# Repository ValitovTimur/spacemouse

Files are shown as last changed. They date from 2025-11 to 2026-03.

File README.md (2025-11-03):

# SpaceMouse (fork): 6‑DOF мышь с 8 Hall‑датчиками и 5 кнопками (без энкодера и подсветки)

**Этот репозиторий — форк** проекта `AndunHH/spacemouse`.

**Целевой стенд:** Arduino Pro Micro (ATmega32U4, 5 V / 16 MHz) + **8 линейных Hall‑датчиков**, **5 физических кнопок** (3 базовые + Fn1 + Fn2). **Энкодера нет. LED‑кольца нет.**

**USB/HID API и формат отчётов полностью совместимы с апстримом** (эмуляция *SpaceMouse Pro Wireless (wired)*). Параметр‑меню, EEPROM и ProgMode по UART сохранены.

---

## Что изменено относительно апстрима

Репозиторий упрощён:

* Оставлены каталоги: **`spacemouse-keys/`**, **`testConfig/`**, **`Reverse-Engineering-Docs/`**, **`modifierFunctions/`**.
* Скрипты/утилиты, не влияющие на текущую сборку, удалены.

Изменения в коде (минимально инвазивно, без ломки API):

* **`spacemouse-keys/config.h`**

  * Профиль аппаратуры «8 Hall + 5 кнопок, без энкодера/LED».
  * Добавлены две новые кнопки в `KEYLIST` и увеличены `NUMKEYS`/`NUMHIDKEYS`.
  * Добавлены индексы модификаторов: `KEY_FN1_IDX`, `KEY_FN2_IDX`.
  * Введены три слоя раскладки HID‑кодов:

    * `BUTTONLIST` — базовый (1/2/3 и соло‑функции Fn).
    * `BUTTONLIST_FN1` — слой для комбо `Fn1 + [1|2|3]`.
    * `BUTTONLIST_FN2` — слой для комбо `Fn2 + [1|2|3]`.
  * Блок чувствительностей/инверсий/гейтов — по реальным замерам из консольного меню (`param::…`).

* **`spacemouse-keys/SpaceMouseHID.cpp`**

  * Переписана **`prepareKeyBytes()`**: корректная обработка **комбинаций** (Fn1/Fn2 + 1/2/3) **без «проскока» базовых кнопок** и **без «сдвоений»**.
  * Удержание (hold) любой кнопки/комбинации корректно **повторяет HID‑репорты** (для Shift/Ctrl/и т.п. на стороне ПК).

> HID‑дескриптор и идентификаторы устройства **не менялись** — драйверы 3Dconnexion/spacenavd видят устройство как раньше.

---

## Аппаратный профиль

* MCU: ATmega32U4 (Pro Micro, 5 V/16 MHz, Caterina).
* Датчики: 8 × линейных Hall (+ магниты/TPU пружины).
* Кнопки: 5 шт. (3 базовые + Fn1 + Fn2).
* Энкодер: **нет**.
* LED/Neopixel: **нет**.

---

## Структура репозитория

```
spacemouse-keys/              ← основной скетч, HID, калибровка, меню, конфиг
  ├─ spacemouse-keys.ino
  ├─ SpaceMouseHID.{h,cpp}    ← HID, сборка битов кнопок (patched)
  ├─ spaceKeys.{h,cpp}        ← чтение/дребезг/состояния клавиш (API без изменений)
  ├─ calibration.{h,cpp}
  ├─ kinematics.{h,cpp}
  ├─ parameterMenu.{h,cpp}
  ├─ config.h                  ← профиль этого форка (patched)
  └─ release.h

testConfig/
Reverse-Engineering-Docs/
modifierFunctions/
```

---

## Сборка и прошивка (Arduino IDE)

1. **Установить пакет SparkFun AVR Boards**
   Arduino IDE → *Board Manager* → найти **SparkFun AVR Boards** → *Install*.

2. **Заменить `boards.txt` из этого форка**
   В корне репозитория лежит `boards.txt`. Скопируй его **поверх** одноимённого файла в директории установленного пакета SparkFun AVR Boards (путь зависит от ОС/IDE), затем **перезапусти Arduino IDE**.

   Примеры путей:

   * **Windows (IDE 2.x):** `C:\Users\<user>\AppData\Local\Arduino15\packages\SparkFun\hardware\avr\<version>\boards.txt`
   * **Windows (IDE 1.8.x portable):** `<Arduino>\hardware\SparkFun\avr\boards.txt`
   * **Linux:** `~/.arduino15/packages/SparkFun/hardware/avr/<version>/boards.txt`
   * **macOS:** `~/Library/Arduino15/packages/SparkFun/hardware/avr/<version>/boards.txt`

3. **Открыть проект**
   `spacemouse-keys/spacemouse-keys.ino`.

4. **Выбрать плату и порт**
   Tools → Board → **SparkFun AVR Boards → Spacemouse (ATmega32U4, 5 V, 16 MHz)**.
   Tools → Port → выбрать твой COM/tty.

5. **Собрать и прошить**
   Нажать **Upload**. Если IDE не поймала окно бутлоадера, дважды быстро нажми **Reset** на Pro Micro (режим Caterina) и повтори Upload.

6. **Проверка через Serial** (необязательно)
   Открой Serial Monitor (115200 бод). Меню отладок/параметров — пункт **30**.

> **Важно:** конфигурация (`config.h`), терминальное меню (30), ProgMode и Serial‑API — **без изменений** и полностью совместимы с апстримом.

---

## Конфигурация: ключевые фрагменты

Ниже — выдержка из рабочего `config.h`. HID‑API полностью совместим с апстримом; расширение — только в части 5 кнопок и Fn‑слоёв.

```c
// Кол-во и пины физических кнопок
#define NUMKEYS    5
#define KEYLIST    {0, 1, 2, 14, 16}   // 3 базовые + Fn1 + Fn2 (под твои GPIO)

// Сколько HID-кнопок реально репортим (биты в 4 байтах отчёта)
#define NUMHIDKEYS 5

// Индексы Fn-кнопок в keyState[] (по порядку из KEYLIST)
#define KEY_FN1_IDX 3
#define KEY_FN2_IDX 4

// Базовый слой (без Fn): 1,2,3 + соло-действия Fn
#define BUTTONLIST      {SM_2,   SM_1,   SM_3,   SM_SHFT, SM_4}

// Слой Fn1: Fn1 + 1/2/3 → альтернативные коды
#define BUTTONLIST_FN1  {SM_FIT, SM_MENU, SM_ROT, SM_SHFT, SM_4}

// Слой Fn2: Fn2 + 1/2/3 → ещё один набор кодов
#define BUTTONLIST_FN2  {SM_CTRL, SM_ESC,  SM_ALT, SM_SHFT, SM_4}
```

Поведение:

* **Одиночная 1/2/3** — отправляется базовый HID‑код.
* **Fn1/Fn2 + 1/2/3** — отправляется **только** код из соответствующего Fn‑слоя (без лишнего базового клика).
* **Fn1/Fn2 в одиночку** — их соло‑действия берутся из `BUTTONLIST` (в примере: `SM_SHFT` и `SM_4`).
* **Удержание** кнопок/комбинаций — HID‑репорты продолжают идти (repeat/hold работает).

Остальной `config.h` (DEADZONE, MIN/MAX, чувствительности, инверсии, дрейф‑компенсация) — по апстриму, значения выставлены по замерам целевого девайса.

---

## Совместимость

* **USB/HID отчёты** идентичны апстриму — драйверы 3Dconnexion (Windows/macOS) и **spacenavd** (Linux) принимают устройство без изменений.
* **Параметр‑меню / EEPROM / ProgMode** — без изменений (меню `30` в сериалке; команды `>p`, `>r`, `>w`, `>s` и т.д.).

---

## Патч‑лист (файлы)

* `spacemouse-keys/config.h`

  * Расширение до 5 кнопок (`NUMKEYS`, `KEYLIST`, `NUMHIDKEYS`).
  * Добавлены `KEY_FN1_IDX`, `KEY_FN2_IDX`.
  * Добавлены `BUTTONLIST`, `BUTTONLIST_FN1`, `BUTTONLIST_FN2`.
  * Обновлены калибровки и чувствительности по реальным замерам.

* `spacemouse-keys/SpaceMouseHID.cpp`

  * Переписана `prepareKeyBytes()` под Fn‑слои; убраны «двойные» клики; корректен hold (повторение отчётов).

> Остальные исходники — как в апстриме; интерфейсы/структуры не менялись.

---

## Известные ограничения

* По умолчанию **отключены** энкодер и LED‑подсветка (можно включить обратно через `config.h`, но профиль форка — «8 Hall + 5 кнопок»).
* При увеличении числа кнопок: обновляйте `NUMKEYS`, `KEYLIST`, `NUMHIDKEYS` и все слои; следите, чтобы индексы Fn указывали на реальные позиции в `KEYLIST`.

---

## Лицензия и атрибуция

Лицензия наследована от апстрима: **CC BY‑NC‑SA 4.0**.

Апстрим: `AndunHH/spacemouse`. 3Dconnexion к проекту не аффилирована; USB‑протокол восстановлен обратной разработкой сообществом.

## Наладка и калибровка (c нуля до «ездит как надо»)

> Целевая аппаратная конфигурация этого форка: **8 HES**, **без энкодера/подсветки**, **5 кнопок (1/2/3 + Fn1/Fn2)**, прошивка — эмуляция **SpaceMouse Pro Wireless (cabled)**. Терминальное меню, ProgMode и формат параметров сохранены.

1. **Проверка разводки HES и полярностей**

   * Открой Serial‑монитор, нажми `Enter`, выбери режим **1** (или **10**) — «raw ADC».
   * Двигая ручку по одной оси, смотри, что шевелятся **ровно нужные пары** каналов (см. `PINLIST`).
   * Если при приближении магнита *значение растёт*, а должно **падать** — инвертируй соответствующую пару в `INVERTLIST` (обычно зеркально: `0&1`, `2&3`, `6&7`, `8&9`).
   * Повтори для всех трёх степеней свободы.

2. **Нулевая точка и «тихий» дрейф**

   * Режим **11** («Zeroing…»). Не трогай ручку, смотри предложенный `DEADZONE` и отметки *Axis not centered?*.
   * Поставь небольшую «мёртвую зону» — **3…6**. В конфиге: `#define DEADZONE N`, или через меню параметров (см. п. 7) → **Write to EEPROM**.

3. **Диапазоны MIN/MAX**

   * Режим **20** на ~20 с: активно покачай/пожми по всем осям.
   * Забери предложенные массивы `MINVALS`/`MAXVALS` и **впиши в `config.h`** (раздел «Third calibration»), **пересобери и залей**.
   * Признак, что диапазон занижен: в режимах 2/3/4 значения «упираются» раньше физического хода.

4. **Чувствительность**

   * Режим **4** (TX/TY/TZ/RX/RY/RZ). Добивайся, чтобы при полном ходе пики были в коридоре **±320…±350**.
   * Тюнинг: `SENS_TX/TY` (линейка), `SENS_PTZ/SENS_NTZ` (плюсовая/минусовая Z отдельно), `SENS_RX/RY/RZ` (повороты).
   * Вспомогательные «ворота»: `GATE_NTZ`, `GATE_RX/RY/RZ` — отрубает мелкий шум вокруг нуля (0 = выкл).

5. **Форма отклика (Modifier)**

   * `MODFUNC=0` — линейка.
   * `MODFUNC=1` — «квазиквадрат»: гасит мелочь вокруг нуля, оставляя контроль на больших отклонениях.
   * `MOD_A` влияет на «приплюснутость» у нуля (1.05…1.4), `MOD_B` — на рост к краю (1.1…1.35 для `MODFUNC=3`, но в этом форке по умолчанию **1**).
   * Проверяй в **3** (центрированные+deadzone) и **4** (скорости).

6. **Оси/инверсии/перестановки**

   * Если в САПР «влево» ощущается «вправо» — правь `INVX/INVY/INVZ` и `INVRX/INVRY/INVRZ`.
   * `SWITCHXY/SWITCHYZ` — обмен осей при надобности.
   * Для Windows + 3DxWare частые пресеты указаны в комментариях рядом с define’ами.

7. **Меню параметров и EEPROM (без перекомпиляции)**

   * Режим **30** → `1` (list), `2` (edit), `4` (write EEPROM), `7` (dump defines).
   * Порядок удобный: `2` — подправил / проверил в **4** — `4` (save) — при желании `7` (скопировал в `config.h`).

8. **Комбо‑кнопки (Fn1/Fn2 + 1/2/3)**

   * В этом форке реализованы слои: **база** (`BUTTONLIST`), **Fn1** (`BUTTONLIST_FN1`), **Fn2** (`BUTTONLIST_FN2`).
   * Соло‑нажатия Fn1/Fn2 отдают свои отдельные действия (настроены в базовом списке по индексам `KEY_FN1_IDX/KEY_FN2_IDX`).
   * Комбинации не «протекают» базовыми нажатиями; удержание поддерживает автоповтор на стороне HID.
   * Кнопки и слои задаются **в `config.h`**: `NUMKEYS`, `KEYLIST`, `NUMHIDKEYS`, `BUTTONLIST`, `BUTTONLIST_FN1`, `BUTTONLIST_FN2`, `KEY_FN1_IDX/KEY_FN2_IDX`.

9. **Дрифт‑компенсация**

   * Оставь мышь в покое: при `COMP_EN=1` нули подравниваются автоматически, не трогая твою «центровку» и чувствительности.
   * Тюнинг: `COMP_WAIT` (ожидание покоя), `COMP_NR` (длина усреднения), `COMP_MDIFF/COMP_CDIFF` (допустимые подвижки/смещения).

10. **Быстрый чек‑лист симптомов**

    * «Подвисает» одна из осей на краях → расширь `MINVALS/MAXVALS`.
    * Мелкая дрожь около нуля → чутка увеличь `DEADZONE` или `GATE_*`; подстрой `MODFUNC`.
    * Комбо срабатывают «двойным» нажатием → проверь актуальные файлы `spaceKeys.*` и `SpaceMouseHID.*` из форка (правки слоя/повтора/маски); при необходимости увеличь `DEBOUNCE_KEYS_MS`.

---

### Ручное центрирование (Fn1+Fn2)

Если устройство уже откалибровано, но «нулевая точка» немного уплыла, можно быстро пересвести ноль без пересборки и без потери чувствительности/диапазонов:

* **Зажмите одновременно Fn1 и Fn2 на ~2 секунды.**
* Сработает «мягкий zeroing»: вызывается та же логика, что и автокомпенсация дрейфа (re‑center), **не трогая** MIN/MAX, чувствительности, маппинг осей и EEPROM.
* Работает в любом режиме (в т.ч. вне меню), безопасно.

> Примечание: Авто‑zeroing (drift compensation) остаётся включённым и продолжает работать по заданным порогам `COMP_*`. Комбинация Fn1+Fn2 — это ручной триггер того же процесса, когда нужно «подровнять» ноль сразу.

## Справочник параметров (меню/EEPROM)

Ниже — параметры, видимые в **mode 30 → list/edit**. Типы: **INT**, **FLOAT**, **BOOL**.

#

### Комбинация Fn1+Fn2 — Zeroing

* **Что делает:** мгновенно инициирует мягкое центрирование (re‑center) как в авто‑компенсации дрейфа.
* **Что не делает:** не сбрасывает `MINVALS`/`MAXVALS`, не меняет `SENS_*`, `INV*`, не пишет в EEPROM.
* **Когда использовать:** если после длительной паузы ощущается микросмещение нуля — зажмите Fn1+Fn2 на ~2s.

## Движение и чувствительность

* **DEADZONE** *(INT)* — ширина «мертвой зоны» по центрированным значениям. Малые шумы в ноль. Реком.: **3…6**.
* **SENS_TX / SENS_TY** *(FLOAT)* — делитель чувствительности по X/Y трансляциям. **Меньше** → чувствительнее.
* **SENS_PTZ / SENS_NTZ** *(FLOAT)* — делители по **+Z / −Z** (раздельная калибровка «вниз/вверх»).
* **SENS_RX / SENS_RY / SENS_RZ** *(FLOAT)* — делители по поворотам (roll/pitch/yaw).
* **GATE_NTZ / GATE_RX / GATE_RY / GATE_RZ** *(INT)* — «ворота» около нуля; всё, что по модулю меньше — принудительно ноль. `0` = выкл.

### Модификатор кривой

* **MODFUNC** *(INT)* — 0: линейка; 1: `|x|^a·sign(x)`; 3: `tan(b·(|x|^a·sign(x)))/tan(b)` (в этом форке обычно 0/1).
* **MOD_A** *(FLOAT)* — экспонента «у нуля» (для 1 и 3). Больше → спокойнее около нуля. Типично **1.10…1.40**.
* **MOD_B** *(FLOAT)* — усиление к краям (для 3). Типично **1.10…1.35**.

### Направления/перестановки

* **INVX / INVY / INVZ / INVRX / INVRY / INVRZ** *(BOOL)* — инвертировать соответствующую ось.
* **SWITCHXY / SWITCHYZ** *(BOOL)* — обмен осей (перетасовать под конкретный софт/привычки).

### Эксклюзивный режим

* **EXCLUSIVE** *(BOOL)* — передавать **либо** трансляцию, **либо** вращение (что крупнее).
* **EXCL_HYST** *(INT)* — гистерезис, чтобы не «щёлкало» туда‑сюда (0 = выкл).
* **EXCL_PRIOZ** *(BOOL)* — «Z‑приоритет» для резистивных джойстиков (для HES обычно **0**).

### Дрифт‑компенсация (HES)

* **COMP_EN** *(BOOL)* — включить авто‑подравнивание нулей.
* **COMP_NR** *(INT)* — сколько выборок усреднять, когда устройство признано неподвижным.
* **COMP_WAIT** *(INT, ms)* — сколько ждать «тишину» перед компенсацией.
* **COMP_MDIFF** *(INT)* — предельная амплитуда дрожи «внутри окна», чтобы считать это дрейфом.
* **COMP_CDIFF** *(INT)* — доп. порог от центра: если ушли дальше — компенсацию не делать (считается реальным нажатием).

### Прочее

* **RAXIS_ECH / RAXIS_STR** — для режима «колесо как ось/клавиши» (у нас выключено, но параметры на месте для совместимости).

> Все эти параметры можно редактировать в **mode 30 → edit**, проверять в **mode 4**, сохранять в EEPROM (**mode 30 → write**), а затем выгружать текущие значения в виде `#define` (**mode 30 → list as defines**) для переноса в `config.h`.

---

> Примеры работы модификаторов кривой и подбор коэффициентов с визуализацией — в `modifierFunctions.html` (локальное HTML‑приложение, интерактивно демонстрирующее работу алгоритмов).

## Компиляция/линковка конфигурации кнопок (compile‑time)

Эти вещи **не** живут в EEPROM и задаются в `spacemouse-keys/config.h`:

* `NUMKEYS`, `KEYLIST` — сколько физических кнопок и на каких пинах.
* `NUMHIDKEYS` — сколько из них отдаём в HID‑массив.
* `BUTTONLIST` — базовый слой (индексы SM_* в HID‑отчёте).
* `BUTTONLIST_FN1`, `BUTTONLIST_FN2` — слои для комбо с Fn1/Fn2.
* `KEY_FN1_IDX`, `KEY_FN2_IDX` — индексы Fn‑кнопок (для соло‑действий и выбора слоя).
* `DEBOUNCE_KEYS_MS` — антидребезг.

После изменения этих `#define` → **пересборка и прошивка** обязательны.

## Button map (вид сверху контроллера)

Вид сверху (ориентир: USB сверху):

```
                                         USB
                                  -................
                KEY1              -              ..
                      .--      .........  . ........
                   .--. -+....                       ....
                  --.  ...        ...-.......-...        ...
                  .--..      ....                  ...       ..
     KEY2    .+.   .      ..                           ..      .
            +. .--     ..                                 ..     .
          --.  .     -.                                     ..     .
          +-. .    ..                .-------.                ..     .
            ..   ..             -.              ...             .    ..
       ... .    ..           ..                     ..           ..   ..
KEY3  .- .-.   ..          ..      .-..     ...       .           ..   ..
      -. ..   ..         .-     ..              ...     .          ..   ..
     .+  ..  ..         ..    ..                   ..    ..         ..   .
     .-+-.   -         ..   ..                      ..    ..        ..   ..
        ..  ..         .   ..                        ..    .         ..   .
       ..   -         -    .                          .    ..        ..   .
       ..   .         .    .                           .   ..         ..  .
       ..  ..         .    .                           -    .         ..  ..
       ..  ..         .    .                           -   ..         ..  ..
       ..  ..         -    .                          ..   ..         ..  .
        .   .         ..   ..                         .    ..         .   .
        ..  .          .    ..                       .    ..         ..   .
        ..  ..          .    ..                    ..    ..          ..  ..
         ..  .           ..    ..                ..     ..          ..   .
         ..   .            .      ..          .-.      -            .   .
          ..   .            ..                      ...            -   ..
           .    .              ..                 -.              -   ..
            ..   .                 .-..     .--.                 .   ..
              .   ..                                           ..   -+.
               .    ..                                       ..    .  --
                 .    .                                    ..   ..  .--
                   ..   ..                              ...    ..+---.   Fn1
                     ..    ...                      ....    ...    *
                        ...    .......       .......    .... --.
                           ....       .......       ...+-  .---
                                ....................     *--       Fn2
```

### Таблица соответствий

| Кнопка | Одиночное (Base) | С Fn1 | С Fn2 |
| --- | --- | --- | --- |
| KEY1 | **1** *(SM_1)* | **MENU** *(SM_MENU)*  | **ESC** *(SM_ESC)* |
| KEY2 | **2** *(SM_2)* | **FIT** *(SM_FIT)* | **CTRL** *(SM_CTRL)*  |
| KEY3 | **3** *(SM_3)* | **LOCK** *(SM_ROT)* | **ALT** *(SM_ALT)* |
| Fn1 | **SHIFT** *(SM_SHFT)* | — | **Fn1+Fn2 = Zeroing** |
| Fn2 | **4** *(SM_4)* | **Fn1+Fn2 = Zeroing** | — |

> **Примечания**
>
> * **Fn‑кнопки** работают как **модификаторы слоёв**: зажатый Fn1 или Fn2 временно переключает KEY1..KEY3 на альтернативные функции из соответствующего слоя. Одиночное нажатие Fn1/Fn2 тоже отправляет своё действие (см. таблицу).
> * **Fn1+Fn2** вместе запускают «Zeroing» (мягкое рецентрирование по дрейфу). Это **не** трогает MIN/MAX, чувствительности `SENS_*`, EEPROM-конфиг и т.п.; только пересчитывается текущий ноль, как при дрейф‑компенсации.
> * Раскладка изменяемая: при необходимости её можно настроить в `spacemouse-keys/config.h` через списки `BUTTONLIST`, `BUTTONLIST_FN1`, `BUTTONLIST_FN2` и индексы `KEY_FN1_IDX/KEY_FN2_IDX`. Для драйвера/ПО соответствия API показаны в скобках *(SM_…)*.

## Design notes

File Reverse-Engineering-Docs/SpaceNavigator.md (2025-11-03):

# Space Navigator
This page contains informations about a 3Dconnexion SpaceNavigator, which has been observed via wireshark:

`sudo modprobe usbmon` 
`sudo wireshark`

Test on update rate of the spacemouse with wireshark and spacenavd on ubuntu. src 1.8.1

## Data transmitted by Space Navigator
First package: (no translation seen here)
`01 00 00 00 00 00 00`

Second package: (rotation around "right down" = "second axis")
`02 00 00 e2 ff 00 00`

Pushing Button 1:
`03 01 00`

Releasing Button 1:
`03 00 00`

Pushing Button 2:
`03 02 00`

Release Button 2:
`03 00 00`

Pushing both buttons at the same time: 
`03 03 00`

If in spnavcfg the LED is turned on, the host sends to 1.8.2
`04 01`

Turning LED off:
`04 00`

## Timing of the data sent by Space Navigator
Report Id 1 for translation is sent.
8 ms later Report Id 2 for rotation is sent.
If keys are pressed: After 8 ms Report Id 3 is sent. Otherwise this is skipped and after 8 ms it restarts with Report Id 1.

This leads to a constant rate of 125 packages per second with alternating report id, as long there non-zero data.

After the last package with non-zero data, translation and rotation and sent three times with only zeros and in the steady 8 ms intervall.

## Device Descriptor of Space Navigator
```
DEVICE DESCRIPTOR
    bLength: 18
    bDescriptorType: 0x01 (DEVICE)
    bcdUSB: 0x0200
    bDeviceClass: Device (0x00)
    bDeviceSubClass: 0
    bDeviceProtocol: 0 (Use class code info from Interface Descriptors)
    bMaxPacketSize0: 8
    idVendor: Logitech, Inc. (0x046d)
    idProduct: 3Dconnexion Space Navigator 3D Mouse (0xc626)
    bcdDevice: 0x0435
    iManufacturer: 1
    iProduct: 2
    iSerialNumber: 0
    bNumConfigurations: 1
```

## HID Report of Space Navigator
See also [the wireshark protocoll](Reverse-Engineering-Docs/SpaceNavigator-Connected-Calibrate.pcapng) for a SpaceNavigator connected and pressed "calibrate" in the windows driver.

The HID following HID descriptor has been decoded with https://eleccelerator.com/usbdescreqparser/ 
```
0x05, 0x01,        // Usage Page (Generic Desktop Ctrls)
0x09, 0x08,        // Usage (Multi-axis Controller)
0xA1, 0x01,        // Collection (Application)
0xA1, 0x00,        //   Collection (Physical)
0x85, 0x01,        //     Report ID (1)
0x16, 0xA2, 0xFE,  //     Logical Minimum (-350)
0x26, 0x5E, 0x01,  //     Logical Maximum (350)
0x36, 0x88, 0xFA,  //     Physical Minimum (-1400)
0x46, 0x78, 0x05,  //     Physical Maximum (1400)
0x55, 0x0C,        //     Unit Exponent (-4)
0x65, 0x11,        //     Unit (System: SI Linear, Length: Centimeter)
0x09, 0x30,        //     Usage (X)
0x09, 0x31,        //     Usage (Y)
0x09, 0x32,        //     Usage (Z)
0x75, 0x10,        //     Report Size (16)
0x95, 0x03,        //     Report Count (3)
0x81, 0x06,        //     Input (Data,Var,Rel,No Wrap,Linear,Preferred State,No Null Position)
0xC0,              //   End Collection
0xA1, 0x00,        //   Collection (Physical)
0x85, 0x02,        //     Report ID (2)
0x09, 0x33,        //     Usage (Rx)
0x09, 0x34,        //     Usage (Ry)
0x09, 0x35,        //     Usage (Rz)
0x75, 0x10,        //     Report Size (16)
0x95, 0x03,        //     Report Count (3)
0x81, 0x06,        //     Input (Data,Var,Rel,No Wrap,Linear,Preferred State,No Null Position)
0xC0,              //   End Collection
0xA1, 0x02,        //   Collection (Logical)
0x85, 0x03,        //     Report ID (3)
0x05, 0x01,        //     Usage Page (Generic Desktop Ctrls)
0x05, 0x09,        //     Usage Page (Button)
0x19, 0x01,        //     Usage Minimum (0x01)
0x29, 0x02,        //     Usage Maximum (0x02)
0x15, 0x00,        //     Logical Minimum (0)
0x25, 0x01,        //     Logical Maximum (1)
0x35, 0x00,        //     Physical Minimum (0)
0x45, 0x01,        //     Physical Maximum (1)
0x75, 0x01,        //     Report Size (1)
0x95, 0x02,        //     Report Count (2)
0x81, 0x02,        //     Input (Data,Var,Abs,No Wrap,Linear,Preferred State,No Null Position)
0x95, 0x0E,        //     Report Count (14)
0x81, 0x03,        //     Input (Const,Var,Abs,No Wrap,Linear,Preferred State,No Null Position)
0xC0,              //   End Collection
0xA1, 0x02,        //   Collection (Logical)
0x85, 0x04,        //     Report ID (4)
0x05, 0x08,        //     Usage Page (LEDs)
0x09, 0x4B,        //     Usage (Generic Indicator)
0x15, 0x00,        //     Logical Minimum (0)
0x25, 0x01,        //     Logical Maximum (1)
0x95, 0x01,        //     Report Count (1)
0x75, 0x01,        //     Report Size (1)
0x91, 0x02,        //     Output (Data,Var,Abs,No Wrap,Linear,Preferred State,No Null Position,Non-volatile)
0x95, 0x01,        //     Report Count (1)
0x75, 0x07,        //     Report Size (7)
0x91, 0x03,        //     Output (Const,Var,Abs,No Wrap,Linear,Preferred State,No Null Position,Non-volatile)
0xC0,              //   End Collection
0x06, 0x00, 0xFF,  //   Usage Page (Vendor Defined 0xFF00)
0x09, 0x01,        //   Usage (0x01)
0xA1, 0x02,        //   Collection (Logical)
0x15, 0x80,        //     Logical Minimum (-128)
0x25, 0x7F,        //     Logical Maximum (127)
0x75, 0x08,        //     Report Size (8)
0x09, 0x3A,        //     Usage (0x3A)
0xA1, 0x02,        //     Collection (Logical)
0x85, 0x05,        //       Report ID (5)
0x09, 0x20,        //       Usage (0x20)
0x95, 0x01,        //       Report Count (1)
0xB1, 0x02,        //       Feature (Data,Var,Abs,No Wrap,Linear,Preferred State,No Null Position,Non-volatile)
0xC0,              //     End Collection
0xA1, 0x02,        //     Collection (Logical)
0x85, 0x06,        //       Report ID (6)
0x09, 0x21,        //       Usage (0x21)
0x95, 0x01,        //       Report Count (1)
0xB1, 0x02,        //       Feature (Data,Var,Abs,No Wrap,Linear,Preferred State,No Null Position,Non-volatile)
0xC0,              //     End Collection
0xA1, 0x02,        //     Collection (Logical)
0x85, 0x07,        //       Report ID (7)
0x09, 0x22,        //       Usage (0x22)
0x95, 0x01,        //       Report Count (1)
0xB1, 0x02,        //       Feature (Data,Var,Abs,No Wrap,Linear,Preferred State,No Null Position,Non-volatile)
0xC0,              //     End Collection
0xA1, 0x02,        //     Collection (Logical)
0x85, 0x08,        //       Report ID (8)
0x09, 0x23,        //       Usage (0x23)
0x95, 0x07,        //       Report Count (7)
0xB1, 0x02,        //       Feature (Data,Var,Abs,No Wrap,Linear,Preferred State,No Null Position,Non-volatile)
0xC0,              //     End Collection
0xA1, 0x02,        //     Collection (Logical)
0x85, 0x09,        //       Report ID (9)
0x09, 0x24,        //       Usage (0x24)
0x95, 0x07,        //       Report Count (7)
0xB1, 0x02,        //       Feature (Data,Var,Abs,No Wrap,Linear,Preferred State,No Null Position,Non-volatile)
0xC0,              //     End Collection
0xA1, 0x02,        //     Collection (Logical)
0x85, 0x0A,        //       Report ID (10)
0x09, 0x25,        //       Usage (0x25)
0x95, 0x07,        //       Report Count (7)
0xB1, 0x02,        //       Feature (Data,Var,Abs,No Wrap,Linear,Preferred State,No Null Position,Non-volatile)
0xC0,              //     End Collection
0xA1, 0x02,        //     Collection (Logical)
0x85, 0x0B,        //       Report ID (11)
0x09, 0x26,        //       Usage (0x26)
0x95, 0x01,        //       Report Count (1)
0xB1, 0x02,        //       Feature (Data,Var,Abs,No Wrap,Linear,Preferred State,No Null Position,Non-volatile)
0xC0,              //     End Collection
0xA1, 0x02,        //     Collection (Logical)
0x85, 0x13,        //       Report ID (19)
0x09, 0x2E,        //       Usage (0x2E)
0x95, 0x01,        //       Report Count (1)
0xB1, 0x02,        //       Feature (Data,Var,Abs,No Wrap,Linear,Preferred State,No Null Position,Non-volatile)
0xC0,              //     End Collection
0xC0,              //   End Collection
0xC0,              // End Collection

// 217 bytes

0000   05 01 09 08 a1 01 a1 00 85 01 16 a2 fe 26 5e 01   .............&^.
0010   36 88 fa 46 78 05 55 0c 65 11 09 30 09 31 09 32   6..Fx.U.e..0.1.2
0020   75 10 95 03 81 06 c0 a1 00 85 02 09 33 09 34 09   u...........3.4.
0030   35 75 10 95 03 81 06 c0 a1 02 85 03 05 01 05 09   5u..............
0040   19 01 29 02 15 00 25 01 35 00 45 01 75 01 95 02   ..)...%.5.E.u...
0050   81 02 95 0e 81 03 c0 a1 02 85 04 05 08 09 4b 15   ..............K.
0060   00 25 01 95 01 75 01 91 02 95 01 75 07 91 03 c0   .%...u.....u....
0070   06 00 ff 09 01 a1 02 15 80 25 7f 75 08 09 3a a1   .........%.u..:.
0080   02 85 05 09 20 95 01 b1 02 c0 a1 02 85 06 09 21   .... ..........!
0090   95 01 b1 02 c0 a1 02 85 07 09 22 95 01 b1 02 c0   ..........".....
00a0   a1 02 85 08 09 23 95 07 b1 02 c0 a1 02 85 09 09   .....#..........
00b0   24 95 07 b1 02 c0 a1 02 85 0a 09 25 95 07 b1 02   $..........%....
00c0   c0 a1 02 85 0b 09 26 95 01 b1 02 c0 a1 02 85 13   ......&.........
00d0   09 2e 95 01 b1 02 c0 c0 c0                        .........
```

# Other related stuff
## Device List for other devices
Check [ANTz wiki](https://github.com/openantz/antz/wiki/3D-Mouse#device-list) for a device list. 
Interestingly, our code is not fully compliant with this list, as we use event#1 and event#2 with 6 byte, despite we are suggesting to be a SpaceMouse Pro Wireless (cabled), which has only one 12 byte event#1.
This seems to be no problem, as our HID descriptor is declaring the values with report id#1 and id#2.

## About relative and absolute input data
[Full discussion](https://github.com/FreeSpacenav/spacenavd/issues/108)
> When I wrote the first version of spacenavd, I only had a space navigator, and the first version of spacenavd only worked with "relative" inputs because that was what the space navigator emitted. I'm saying "relative" in quotes because they weren't really relative, they were just reported as such, but the values were always absolute displacements per axis. 3Dconnexion probably realized at some stage that reporting them as "relative" is incorrect, and changed to absolute in newer devices. 
>
> I'm pretty sure all modern 3Dconnexion devices report absolute axis usage.

> The original Space Navigator reports it's data as relative positions. The original Space Navigator is very sensitive and is jiggling a lot i.e. the same value is only send repeatedly very for some milli-seconds.
>
> My emulated "SpaceMouse Pro Wireless (cabled)" (or at least our inherited) hid report descriptor reports absolute values
Our emulation is very sturdy and if you hold it in position, the same value are easily calculate for a second.
>
> When using spacenavd and the simple example, cube or even in FreeCAD:
>
>Relative reports are evaluated with every event, even if they are the same as before.
Absolute reports are only evaluated, if they differ from the previous report. This is merely visible with the SpaceNavigator, but is very annoying for our emulation, as it is reporting same values very often. I didn't figured out, if this dropping of events is done by spacenavd or linux itself...

> Solution: Change our emulated mouse to Relative Positions, even if this is not "up to date". But it avoids the necessity to jiggle the values.

## HID descriptor of a spacemouse wireless
See [SpaceMouseWireless.md](SpaceMouseWireless.md)

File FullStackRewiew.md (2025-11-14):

# Полный обзор правок и модификаций, которые нужно ввести.

## Схемотехника

  1. Однозначно фильтрацию входного питания. LC фильтр, защита от статики,
     перенапряжения, переполюсовки.
  2. Отделить ответвление питания датчиков Холла. LC фильтр, защита по току.
     Свивка жгута питания.
  3. Фильтр питания НА КАЖДОМ сенсоре прям у входа.
  4. Фильтрация выхода КАЖДОГО сенсора у входа в АЦП. Срезать все, что выше
     200 Гц. Точную частоту прикинуть исходя не из максимальной частоты
     перемещения джойстика (она крайне низка), а из времени фронта сигнала
     при максимальном создаваемом ускорении. Если выставить фильтр 10Гц
     (сомневаюсь что кто-то сможет дергать рукоятку быстрее), то управление
     может стать ватным, т.к. при быстром перемещении рукоятки, выходной сигнал
     будет дольше догонять уровень реального сигнала и управление будет ватным.
     Поэтому, смотреть частоту среза по фронту максимального ускорения. Это
     будет относительно грубый фильтр, чисто чтобы защитить от помех с питания
     и ВЧ наводок. Дальнейшая фильтрация в ПО.
  5. Свивка КАЖДОГО сигнального выхода сенсора с землей.
  6. Можно подумать о усилении и смещении полезного сигнала, для растягивания
     его на полный диапазон АЦП. Но не думаю что это нужно.
     6.1. Это приведет к сложной и индивидуальной настройке смещения под каждый
          сенсор, каждой мышке. Ну либо придумывать схемотехнику с ЦАП, где
          контроллер сам будет выставлять напряжение смещения и усиления.
     6.2. Схемотехника усложняется и увеличивается плата.
     Пока-что этот пункт не исполнять. Точности хватает и при текущей, дерьмовой
     схемоте, и на этапе первого прототипа не имеет смысла так вылизывать ее.
  7. Кол-во кнопок увеличить, сделать равным оригиналу. Кнопки тоже свивками,
     RC-фильтром и защитой по току. Все-таки выводы цифровые, в случае чего
     и пожечь можно.
  8. Обдумать возможность размещения ВСЕГО что есть, на плате, прямо под
     шайбой. Это кажется более чем осуществивым.

## ПО:

  По сути, тут уже все сделано. Я уже добавил возможность использования
  дополнительных 6-ти кнопок через комбинации.
  Нужно добавить еще программную фильтрацию данных (чтобы убрать дрож в процессе
  перемещения и убрать дрожание при затухающих колебаниях рукоятки).
  Фильтрацию разумно разместить не напрямую на анлоговых данных, а между уже
  рассчитаными перемещениями\вращениями по координатам и дополнительными
  модиффикаторами перемещений, нелинейных зависимостей и т.д.
  То есть, фильтровать не сам сигнал, а рассчитаные величины. Это более
  предсказуемо.

## Эргономика

  1. В основном, вся работа уже проделана.
     1.1. Рукоятку - скопировать.
     1.2. Основание рукоятки - скопировать (вот это углубление, в которое она
          входит).
     1.3. Пружину - однозначно скопировать. Идея печатной пружины и на столько
          простой механики - это супер круто. Пожал бы руку тому, кто догадался
          и провел эксперименты.
     1.4. Основание - переработать.
          1.4.1. Кнопки - увеличить кол-во, сменить сам тип кнопки на что-то
                 более мягкое, и сместить под пальцы.
          1.4.2. Сделать подставку под руку. В идеале - съемную.
                 Например, сделать ее круговой подставкой, в которую помещается
                 текущая "шайба". Можно попробовать подумать над смещением
                 кнопок на нее, и подключение этих кнопок через POGO пины.
                 ЕБАТЬ! ВОТ ОНО! Можно оставить 5 кнопок на шайбе, а остальные
                 переместить на подставку и Pogo пины.
                 Тогда хоткеи будут полностью совместимы.
  2. Чехол. Однозначно нужно сделать, скорее всего из TPU, должен закрывать
     рукоятку, но не касаться ее, а вот на шайбу должен натягиваться, чтобы
     за нее держаться. Можно сделать сужение, чтобы оно зацеплялось за основание.

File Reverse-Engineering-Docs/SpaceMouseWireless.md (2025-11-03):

# SpaceMouse Wireless
This page contains informations about a 3Dconnexion Space Mouse Wireless, which has been observed via wireshark:

SpaceMouse Wirelss HID Report
Recorded with Wireshark. 
Decoded with https://eleccelerator.com/usbdescreqparser/

## Update Rate
In move_and_rot.pcapng:
The translation and rotation seem to be sent at a speed of 12.5 packets each 200 ms = 62,5 packets/s = 16 ms update rate.

## Buttons and LEDs
Not further analysed jet, but seems to conform to [SpaceNavigator.](SpaceNavigator.md). I.e.: Report 3 rot keys, Report 4 for LED.

## Other findings
From other records: Report 0x17 reports the battery

    Report ID: 0x17
    0110 0100 = Usage: Battery Strength: 100 
    Vendor Data: 01
    Padding: 00

## Device Descriptor
```
DEVICE DESCRIPTOR
    bLength: 18
    bDescriptorType: 0x01 (DEVICE)
    bcdUSB: 0x0200
    bDeviceClass: Device (0x00)
    bDeviceSubClass: 0
    bDeviceProtocol: 0 (Use class code info from Interface Descriptors)
    bMaxPacketSize0: 32
    idVendor: 3Dconnexion (0x256f)
    idProduct: SpaceMouse Wireless (cabled) (0xc62e)
    bcdDevice: 0x0441
    iManufacturer: 1
    iProduct: 2
    iSerialNumber: 0
    bNumConfigurations: 1
```

## HID Report of SpaceMouse Wireless
```
0x05, 0x01,        // Usage Page (Generic Desktop Ctrls)
0x09, 0x08,        // Usage (Multi-axis Controller)
0xA1, 0x01,        // Collection (Application)
0xA1, 0x00,        //   Collection (Physical)
0x85, 0x01,        //     Report ID (1)
0x16, 0xA2, 0xFE,  //     Logical Minimum (-350)
0x26, 0x5E, 0x01,  //     Logical Maximum (350)
0x36, 0x88, 0xFA,  //     Physical Minimum (-1400)
0x46, 0x78, 0x05,  //     Physical Maximum (1400)
0x55, 0x0C,        //     Unit Exponent (-4)
0x65, 0x11,        //     Unit (System: SI Linear, Length: Centimeter)
0x09, 0x30,        //     Usage (X)
0x09, 0x31,        //     Usage (Y)
0x09, 0x32,        //     Usage (Z)
0x09, 0x33,        //     Usage (Rx)
0x09, 0x34,        //     Usage (Ry)
0x09, 0x35,        //     Usage (Rz)
0x75, 0x10,        //     Report Size (16)
0x95, 0x06,        //     Report Count (6)
0x81, 0x02,        //     Input (Data,Var,Abs,No Wrap,Linear,Preferred State,No Null Position)
0xC0,              //   End Collection
0xA1, 0x02,        //   Collection (Logical)
0x85, 0x03,        //     Report ID (3)
0x05, 0x01,        //     Usage Page (Generic Desktop Ctrls)
0x05, 0x09,        //     Usage Page (Button)
0x19, 0x01,        //     Usage Minimum (0x01)
0x29, 0x02,        //     Usage Maximum (0x02)
0x15, 0x00,        //     Logical Minimum (0)
0x25, 0x01,        //     Logical Maximum (1)
0x35, 0x00,        //     Physical Minimum (0)
0x45, 0x01,        //     Physical Maximum (1)
0x75, 0x01,        //     Report Size (1)
0x95, 0x02,        //     Report Count (2)
0x81, 0x02,        //     Input (Data,Var,Abs,No Wrap,Linear,Preferred State,No Null Position)
0x95, 0x0E,        //     Report Count (14)
0x81, 0x03,        //     Input (Const,Var,Abs,No Wrap,Linear,Preferred State,No Null Position)
0xC0,              //   End Collection
0xA1, 0x02,        //   Collection (Logical)
0x85, 0x04,        //     Report ID (4)
0x05, 0x08,        //     Usage Page (LEDs)
0x09, 0x4B,        //     Usage (Generic Indicator)
0x15, 0x00,        //     Logical Minimum (0)
0x25, 0x01,        //     Logical Maximum (1)
0x95, 0x01,        //     Report Count (1)
0x75, 0x01,        //     Report Size (1)
0x91, 0x02,        //     Output (Data,Var,Abs,No Wrap,Linear,Preferred State,No Null Position,Non-volatile)
0x95, 0x01,        //     Report Count (1)
0x75, 0x07,        //     Report Size (7)
0x91, 0x03,        //     Output (Const,Var,Abs,No Wrap,Linear,Preferred State,No Null Position,Non-volatile)
0xC0,              //   End Collection
0xA1, 0x02,        //   Collection (Logical)
0x85, 0x17,        //     Report ID (23)
0x15, 0x00,        //     Logical Minimum (0)
0x25, 0x64,        //     Logical Maximum (100)
0x55, 0x00,        //     Unit Exponent (0)
0x65, 0x00,        //     Unit (None)
0x05, 0x06,        //     Usage Page (Generic Dev Ctrls)
0x09, 0x20,        //     Usage (Battery Strength)
0x75, 0x08,        //     Report Size (8)
0x95, 0x01,        //     Report Count (1)
0x81, 0x02,        //     Input (Data,Var,Abs,No Wrap,Linear,Preferred State,No Null Position)
0x15, 0x00,        //     Logical Minimum (0)
0x25, 0x01,        //     Logical Maximum (1)
0x06, 0x00, 0xFF,  //     Usage Page (Vendor Defined 0xFF00)
0x09, 0x27,        //     Usage (0x27)
0x75, 0x01,        //     Report Size (1)
0x95, 0x01,        //     Report Count (1)
0x81, 0x02,        //     Input (Data,Var,Abs,No Wrap,Linear,Preferred State,No Null Position)
0x75, 0x07,        //     Report Size (7)
0x81, 0x03,        //     Input (Const,Var,Abs,No Wrap,Linear,Preferred State,No Null Position)
0xC0,              //   End Collection
0x06, 0x00, 0xFF,  //   Usage Page (Vendor Defined 0xFF00)
0x09, 0x01,        //   Usage (0x01)
0xA1, 0x02,        //   Collection (Logical)
0x15, 0x80,        //     Logical Minimum (-128)
0x25, 0x7F,        //     Logical Maximum (127)
0x75, 0x08,        //     Report Size (8)
0x09, 0x3A,        //     Usage (0x3A)
0xA1, 0x02,        //     Collection (Logical)
0x85, 0x05,        //       Report ID (5)
0x09, 0x20,        //       Usage (0x20)
0x95, 0x01,        //       Report Count (1)
0xB1, 0x02,        //       Feature (Data,Var,Abs,No Wrap,Linear,Preferred State,No Null Position,Non-volatile)
0xC0,              //     End Collection
0xA1, 0x02,        //     Collection (Logical)
0x85, 0x06,        //       Report ID (6)
0x09, 0x21,        //       Usage (0x21)
0x95, 0x01,        //       Report Count (1)
0xB1, 0x02,        //       Feature (Data,Var,Abs,No Wrap,Linear,Preferred State,No Null Position,Non-volatile)
0xC0,              //     End Collection
0xA1, 0x02,        //     Collection (Logical)
0x85, 0x07,        //       Report ID (7)
0x09, 0x22,        //       Usage (0x22)
0x95, 0x01,        //       Report Count (1)
0xB1, 0x02,        //       Feature (Data,Var,Abs,No Wrap,Linear,Preferred State,No Null Position,Non-volatile)
0xC0,              //     End Collection
0xA1, 0x02,        //     Collection (Logical)
0x85, 0x08,        //       Report ID (8)
0x09, 0x23,        //       Usage (0x23)
0x95, 0x07,        //       Report Count (7)
0xB1, 0x02,        //       Feature (Data,Var,Abs,No Wrap,Linear,Preferred State,No Null Position,Non-volatile)
0xC0,              //     End Collection
0xA1, 0x02,        //     Collection (Logical)
0x85, 0x09,        //       Report ID (9)
0x09, 0x24,        //       Usage (0x24)
0x95, 0x07,        //       Report Count (7)
0xB1, 0x02,        //       Feature (Data,Var,Abs,No Wrap,Linear,Preferred State,No Null Position,Non-volatile)
0xC0,              //     End Collection
0xA1, 0x02,        //     Collection (Logical)
0x85, 0x0A,        //       Report ID (10)
0x09, 0x25,        //       Usage (0x25)
0x95, 0x07,        //       Report Count (7)
0xB1, 0x02,        //       Feature (Data,Var,Abs,No Wrap,Linear,Preferred State,No Null Position,Non-volatile)
0xC0,              //     End Collection
0xA1, 0x02,        //     Collection (Logical)
0x85, 0x0B,        //       Report ID (11)
0x09, 0x26,        //       Usage (0x26)
0x95, 0x01,        //       Report Count (1)
0xB1, 0x02,        //       Feature (Data,Var,Abs,No Wrap,Linear,Preferred State,No Null Position,Non-volatile)
0xC0,              //     End Collection
0xA1, 0x02,        //     Collection (Logical)
0x85, 0x13,        //       Report ID (19)
0x09, 0x2E,        //       Usage (0x2E)
0x95, 0x01,        //       Report Count (1)
0xB1, 0x02,        //       Feature (Data,Var,Abs,No Wrap,Linear,Preferred State,No Null Position,Non-volatile)
0xC0,              //     End Collection
0xA1, 0x02,        //     Collection (Logical)
0x85, 0x19,        //       Report ID (25)
0x09, 0x31,        //       Usage (0x31)
0x95, 0x04,        //       Report Count (4)
0xB1, 0x02,        //       Feature (Data,Var,Abs,No Wrap,Linear,Preferred State,No Null Position,Non-volatile)
0xC0,              //     End Collection
0xA1, 0x02,        //     Collection (Logical)
0x85, 0x1A,        //       Report ID (26)
0x09, 0x32,        //       Usage (0x32)
0x95, 0x07,        //       Report Count (7)
0xB1, 0x02,        //       Feature (Data,Var,Abs,No Wrap,Linear,Preferred State,No Null Position,Non-volatile)
0xC0,              //     End Collection
0xC0,              //   End Collection
0xC0,              // End Collection
// 270 bytes
```

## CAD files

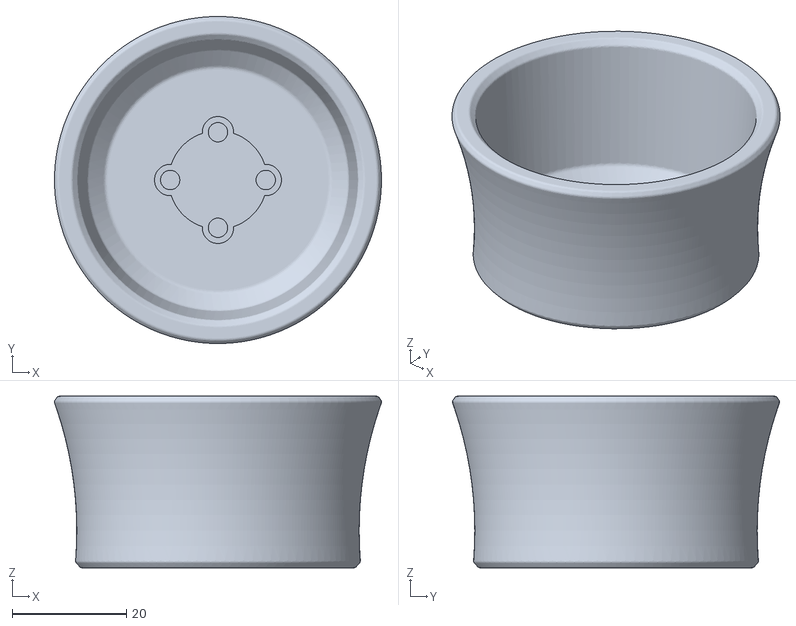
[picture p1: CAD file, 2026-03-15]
3D/Spacemouse+V1+bbla1_stls/obj_5_Knob.stl
57.1 x 57.1 x 30.0

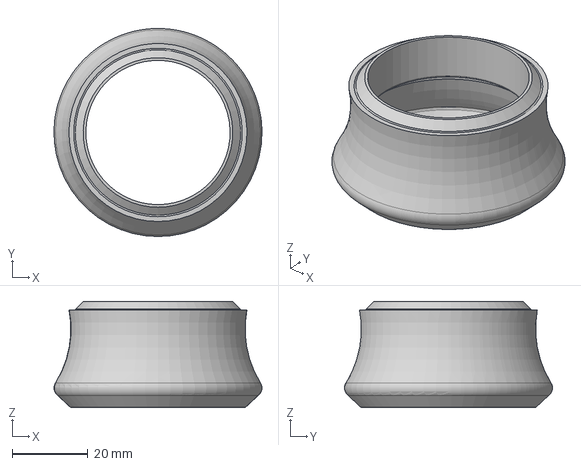
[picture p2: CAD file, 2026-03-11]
3D/TestPrint/Handle.stp
54.8 x 54.8 x 28.0 mm

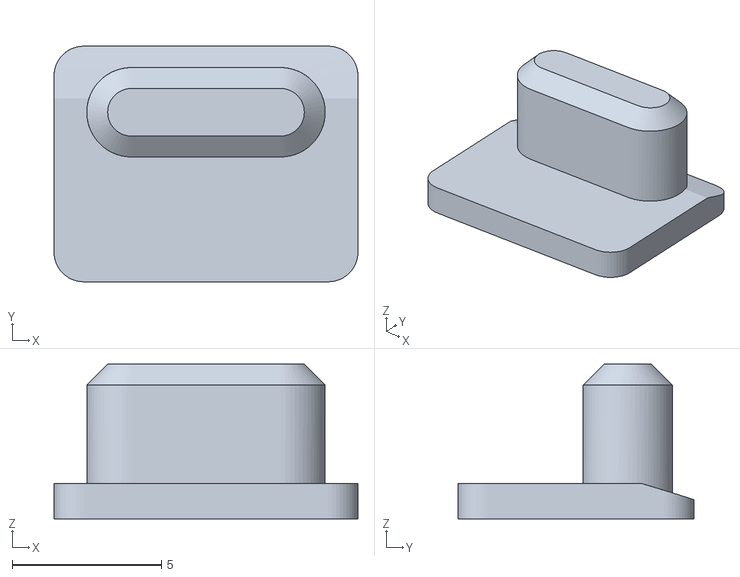
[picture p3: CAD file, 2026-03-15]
3D/Spacemouse+V1+bbla1_stls/obj_4_small buttons.stl
10.2 x 7.91 x 5.19

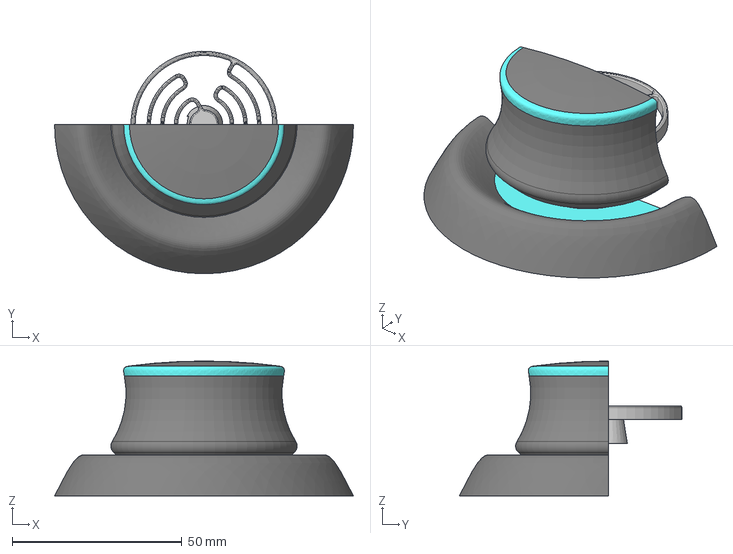
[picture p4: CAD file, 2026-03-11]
3D/TestPrint/SpaceMouse.stp
88.0 x 65.5 x 39.7 mm

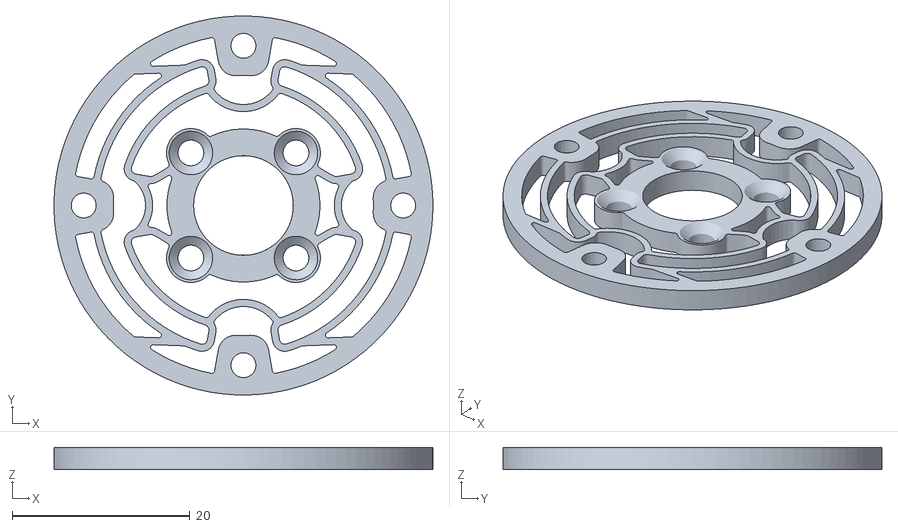
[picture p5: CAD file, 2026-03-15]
3D/Spacemouse+V1+bbla1_stls/obj_22_medium spring.stl
42.6 x 42.6 x 2.50

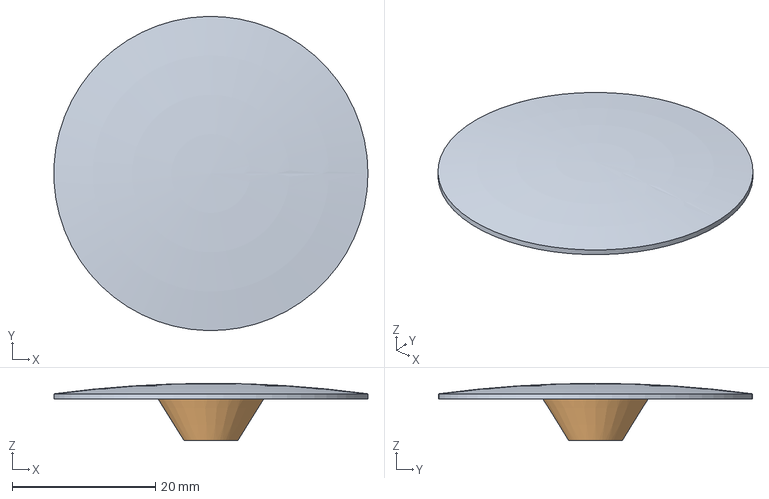
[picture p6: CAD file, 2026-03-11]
3D/TestPrint/HandleCap.stp
43.9 x 43.9 x 8.01 mm

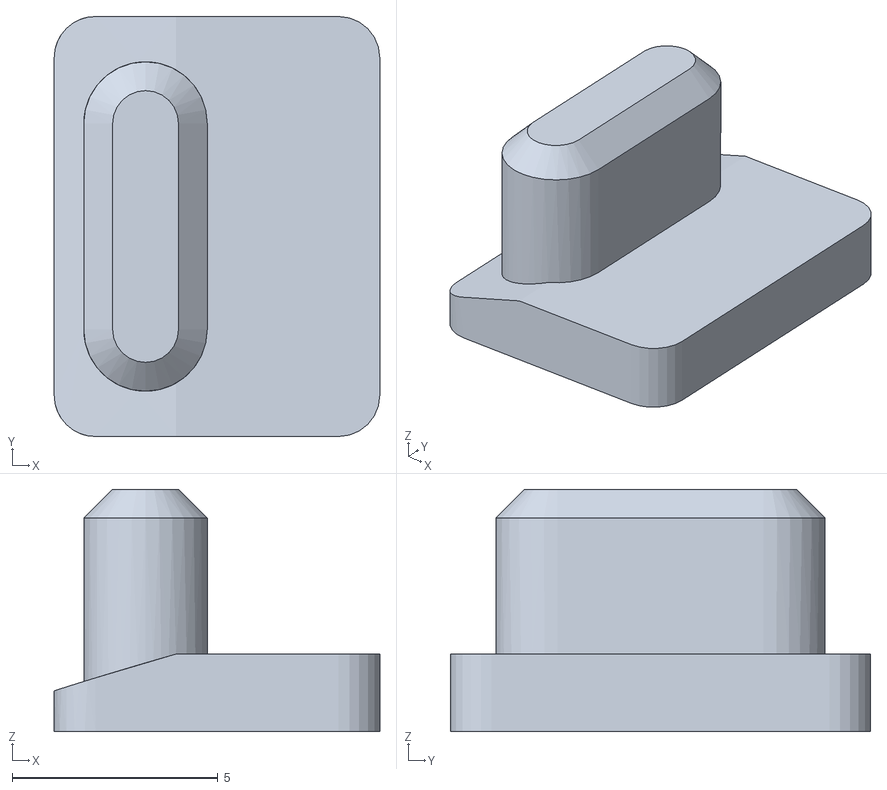
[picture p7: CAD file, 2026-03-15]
3D/Spacemouse+V1+bbla1_stls/obj_23_button 1.stl
7.91 x 10.2 x 5.89

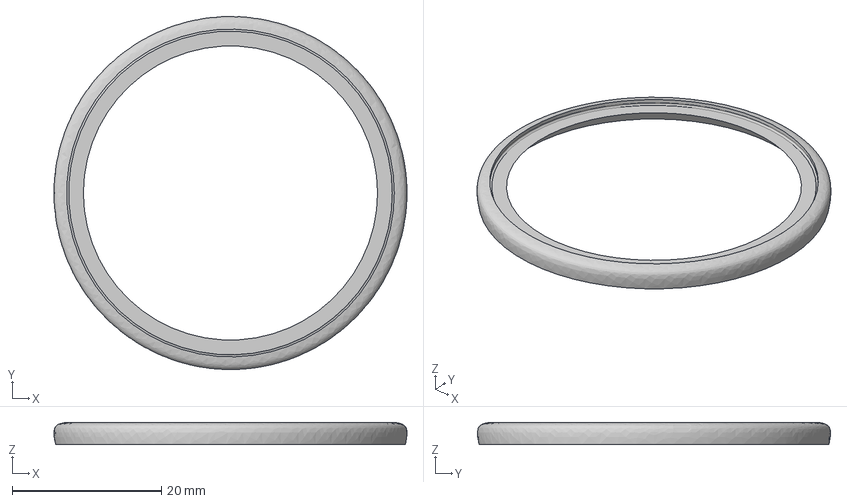
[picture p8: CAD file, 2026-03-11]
3D/TestPrint/HandleRing.stp
47.3 x 47.3 x 3.00 mm

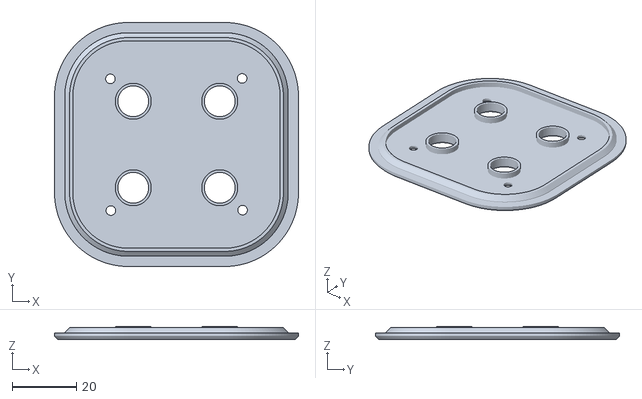
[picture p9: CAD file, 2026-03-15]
3D/Spacemouse+V1+bbla1_stls/obj_7_base cap.stl
76.0 x 76.0 x 4.00

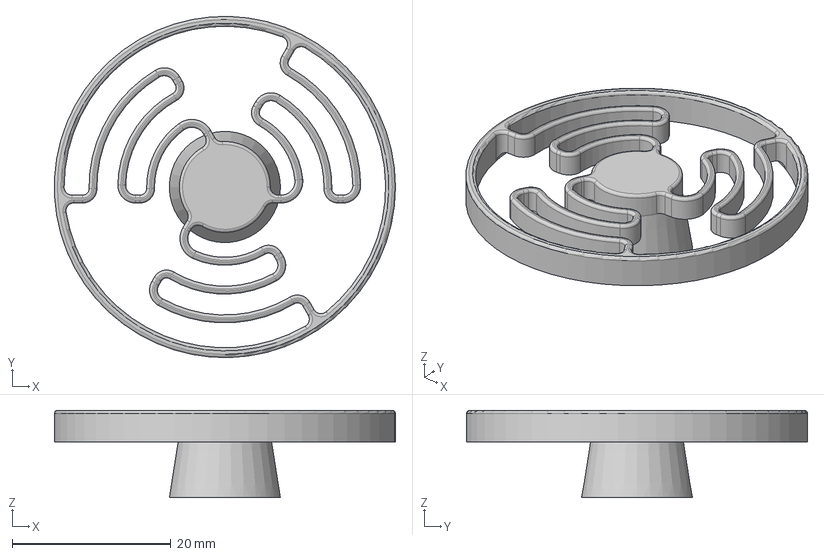
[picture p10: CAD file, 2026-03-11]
3D/TestPrint/Spring.stp
43.0 x 43.0 x 11.0 mm

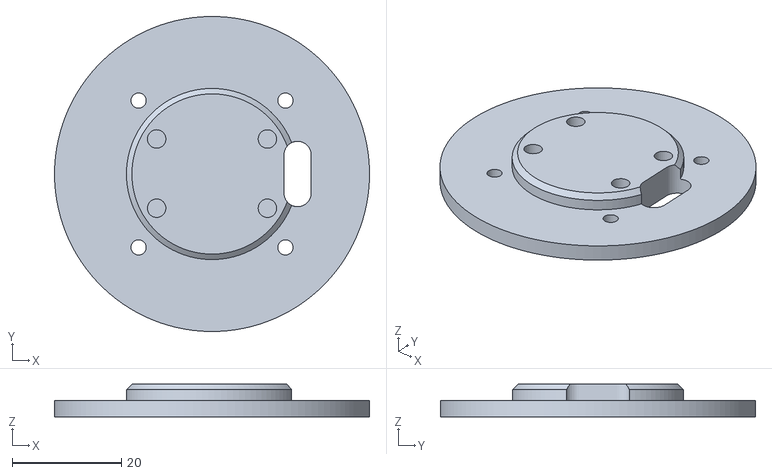
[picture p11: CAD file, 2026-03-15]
3D/Spacemouse+V1+bbla1_stls/obj_10_top support.stl
57.8 x 57.8 x 6.00

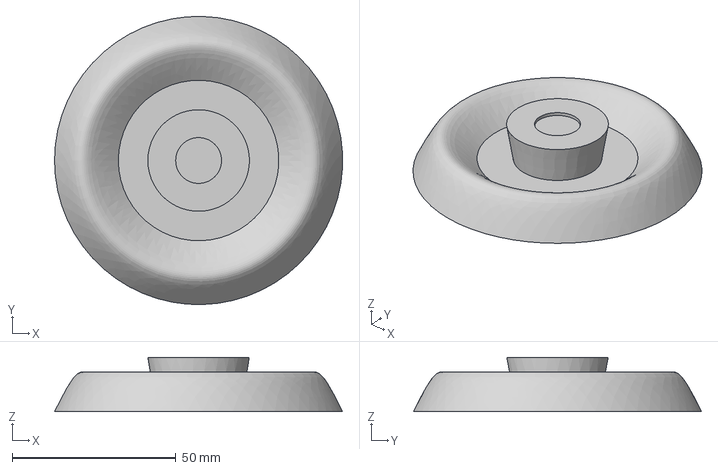
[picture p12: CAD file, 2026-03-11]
3D/TestPrint/Base.stp
87.9 x 88.0 x 16.5 mm

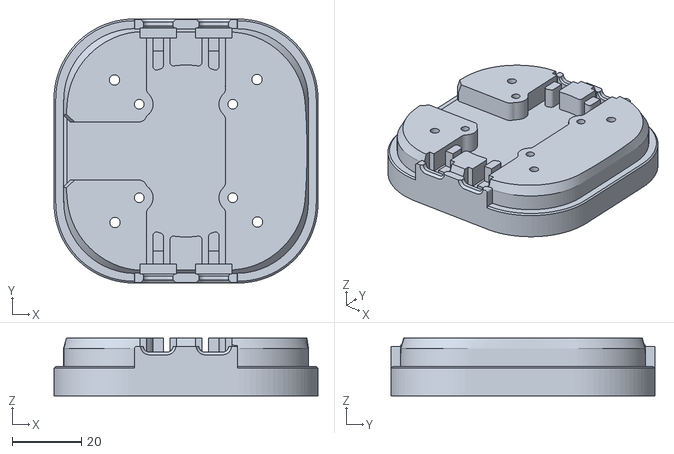
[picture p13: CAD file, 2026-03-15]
3D/Spacemouse+V1+bbla1_stls/obj_13_base 2.5 più.stl
76.0 x 76.0 x 16.6

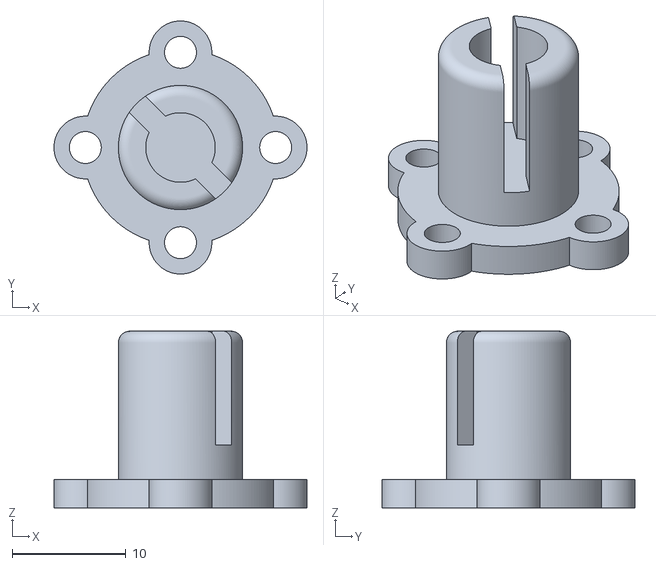
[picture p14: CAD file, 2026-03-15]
3D/Spacemouse+V1+bbla1_stls/obj_24_magnet 1.stl
22.2 x 22.2 x 15.5

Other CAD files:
3D/Spacemouse+V1+bbla1_stls/obj_2_small buttons.stl
3D/Spacemouse+V1+bbla1_stls/obj_25_button 2.stl
3D/Spacemouse+V1+bbla1_stls/obj_26_magnet 2.stl
3D/Spacemouse+V1+bbla1_stls/obj_28_magnet 4.stl
3D/Spacemouse+V1+bbla1_stls/obj_11_standard base.stl
3D/Spacemouse+V1+bbla1_stls/obj_12_base 2.5 più.stl
3D/Spacemouse+V1+bbla1_stls/obj_14_standard base.stl
3D/Spacemouse+V1+bbla1_stls/obj_15_BASE NO.stl
3D/Spacemouse+V1+bbla1_stls/obj_16_BASE NO.stl
3D/Spacemouse+V1+bbla1_stls/obj_17_high base.stl
3D/Spacemouse+V1+bbla1_stls/obj_18_high base.stl
3D/Spacemouse+V1+bbla1_stls/obj_19_internal structure.stl
3D/Spacemouse+V1+bbla1_stls/obj_1_Body125.stl
3D/Spacemouse+V1+bbla1_stls/obj_20_hard spring.stl
3D/Spacemouse+V1+bbla1_stls/obj_21_soft spring.stl
3D/Spacemouse+V1+bbla1_stls/obj_27_magnet 3.stl
3D/Spacemouse+V1+bbla1_stls/obj_29_button 3.stl
3D/Spacemouse+V1+bbla1_stls/obj_30_button 4.stl
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

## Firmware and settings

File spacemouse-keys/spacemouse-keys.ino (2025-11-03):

// This is the source code for the open source space mouse with keys.
// Please read the introduction and history with all contributors here:
// https://github.com/AndunHH/spacemouse

// One good starting point is the work and video by TeachingTech: https://www.printables.com/de/model/864950-open-source-spacemouse-space-mushroom-remix
// Then follow along on github, how we reached this state of the source code.

#include <Arduino.h>

// The user specific settings, like pin mappings or special configuration variables and sensitivities are stored in config.h.
// Please open config_sample.h, adjust your settings and save it as config.h
#include "config.h"
#include "parameterMenu.h"

// Include inbuilt Arduino HID library by NicoHood: https://github.com/NicoHood/HID
#include "HID.h"

// header file for calibration output and helper routines
#include "calibration.h"

// header to calculate the kinematics of the mouse
#include "kinematics.h"

// header file for reading the keys
#include "spaceKeys.h"

// header for HID emulation of the spacemouse
#include "SpaceMouseHID.h"

#if ROTARY_AXIS > 0 or ROTARY_KEYS > 0
// if an encoder wheel is used
#include "encoderWheel.h"
#endif

#ifdef LEDRING
#include "ledring.h"
#endif

void setup();
void loop();
#ifdef LEDpin
void lightSimpleLED(boolean light);
#endif
#ifdef HALLEFFECT
void setAnalogReferenceVoltage(int dbg);
#endif

// stores the raw analog values from the joysticks
int rawReads[8];

// stores the values from the joysticks after zeroing and mapping
int centered[8];

// Centerpoints store the zero position of the joysticks
int centerPoints[8];





// === FN1+FN2 zero hotkey state ===
static bool g_fnZeroPending = false;
static unsigned long g_fnZeroStart = 0;
static unsigned long g_fnZeroCooldownUntil = 0;





// Offsets store the drift-compensation values of the joysticks
int offsets[8];

// Resulting calculated velocities / movements
// int16_t to match what the HID protocol expects.
int16_t velocity[6];

// global parameters (also stored in EEPROM)
ParamStorage parStorage;

ParamData par = { .values      = &parStorage,
                  .description = {
                    {PARAM_TYPE_BOOL,  "",            NULL                              }, // param 0 is unused
                    {PARAM_TYPE_INT,   "DEADZONE",    &parStorage.deadzone              }, //       1
                    {PARAM_TYPE_FLOAT, "SENS_TX",     &parStorage.transX_sensitivity    }, //       2
                    {PARAM_TYPE_FLOAT, "SENS_TY",     &parStorage.transY_sensitivity    }, //       3
                    {PARAM_TYPE_FLOAT, "SENS_PTZ",    &parStorage.pos_transZ_sensitivity}, //       4
                    {PARAM_TYPE_FLOAT, "SENS_NTZ",    &parStorage.neg_transZ_sensitivity}, //       5
                    {PARAM_TYPE_FLOAT, "GATE_NTZ",    &parStorage.gate_neg_transZ       }, //       6
                    {PARAM_TYPE_INT,   "GATE_RX",     &parStorage.gate_rotX             }, //       7
                    {PARAM_TYPE_INT,   "GATE_RY",     &parStorage.gate_rotY             }, //       8
                    {PARAM_TYPE_INT,   "GATE_RZ",     &parStorage.gate_rotZ             }, //       9
                    {PARAM_TYPE_FLOAT, "SENS_RX",     &parStorage.rotX_sensitivity      }, //      10
                    {PARAM_TYPE_FLOAT, "SENS_RY",     &parStorage.rotY_sensitivity      }, //      11
                    {PARAM_TYPE_FLOAT, "SENS_RZ",     &parStorage.rotZ_sensitivity      }, //      12
                    {PARAM_TYPE_INT,   "MODFUNC",     &parStorage.modFunc               }, //      13
                    {PARAM_TYPE_FLOAT, "MOD_A",       &parStorage.slope_at_zero         }, //      14
                    {PARAM_TYPE_FLOAT, "MOD_B",       &parStorage.slope_at_end          }, //      15
                    {PARAM_TYPE_BOOL,  "INVX",        &parStorage.invX                  }, //      16
                    {PARAM_TYPE_BOOL,  "INVY",        &parStorage.invY                  }, //      17
                    {PARAM_TYPE_BOOL,  "INVZ",        &parStorage.invZ                  }, //      18
                    {PARAM_TYPE_BOOL,  "INVRX",       &parStorage.invRX                 }, //      19
                    {PARAM_TYPE_BOOL,  "INVRY",       &parStorage.invRY                 }, //      20
                    {PARAM_TYPE_BOOL,  "INVRZ",       &parStorage.invRZ                 }, //      21
                    {PARAM_TYPE_BOOL,  "SWITCHXY",    &parStorage.switchXY              }, //      22
                    {PARAM_TYPE_BOOL,  "SWITCHYZ",    &parStorage.switchYZ              }, //      23
                    {PARAM_TYPE_BOOL,  "EXCLUSIVE",   &parStorage.exclusiveMode         }, //      24
                    {PARAM_TYPE_INT,   "EXCL_HYST",   &parStorage.exclusiveHysteresis   }, //      25
                    {PARAM_TYPE_BOOL,  "EXCL_PRIOZ",  &parStorage.prioZexclusiveMode    }, //      26
                    {PARAM_TYPE_BOOL,  "COMP_EN",     &parStorage.compEnabled           }, //      27
                    {PARAM_TYPE_INT,   "COMP_NR",     &parStorage.compNoOfPoints        }, //      28
                    {PARAM_TYPE_INT,   "COMP_WAIT",   &parStorage.compWaitTime          }, //      29
                    {PARAM_TYPE_INT,   "COMP_MDIFF",  &parStorage.compMinMaxDiff        }, //      30
                    {PARAM_TYPE_INT,   "COMP_CDIFF",  &parStorage.compCenterDiff        }, //      31
                    {PARAM_TYPE_INT,   "RAXIS_ECH",   &parStorage.rotAxisEchos          }, //      32
                    {PARAM_TYPE_INT,   "RAXIS_STR",   &parStorage.rotAxisSimStrength    }  //      33
                  }
                };

//store raw value of the keys, without debouncing
int keyVals[NUMKEYS];

// key event, after debouncing. It is 1 only for a single sample
uint8_t keyOut[NUMKEYS];

// state of the key, which stays 1 as long as the key is pressed
uint8_t keyState[NUMKEYS];


/**
 * @brief Setup the SpaceMouse, called by system-start
 */
void setup() {
  // Get parameters from EEPROM
  #if PARAM_IN_EEPROM > 0
  getParametersFromEEPROM(par);
  #endif

  // setup the keys e.g. to internal pull-ups
  #if NUMKEYS > 0
  setupKeys();
  #endif

  #ifdef HALLEFFECT
  // Set the ADC reference voltage to 2,56V if HALLEFFECT is defined, 5V otherwise.
  // It is important the reference Voltage is set before the Zeroing of the sensors is executed.
  setAnalogReferenceVoltage(0);
  #endif

  // setup Serial for debugging
  // Serial.begin(115200); // irrelevant for Arduino Micro-platform because the baudrate is set by the connected PC
  Serial.setTimeout(30000);  // the serial interface will wait for new menu number for max.30s

  // Read idle/centre positions for joysticks.
  // zero the joystick position 500 times (takes approx. 480 ms)
  // during setup() we are not interested in the debug output: debugFlag = false
  busyZeroing(centerPoints, 750, false);
  for(int i=0; i<8; i++){offsets[i] = 0;}

  #if ROTARY_AXIS > 0 or ROTARY_KEYS > 0
  initEncoderWheel();
  #endif

  #ifdef LEDpin
  #ifdef LEDRING
  initLEDring();
  #else
  // configure LED output for simple LED
  pinMode(LEDpin, OUTPUT);
  #endif
  #endif
}


/**
 * @brief Main-loop of the SpaceMouse, called cyclic by system
 */
void loop() {
  // the debug mode can be set during runtime via the serial interface. See config.h for a description of the different debug modes.
  static int  debug     = STARTDEBUG;
  static bool showMenu  = false;

  //--- check if the user entered a debug mode via serial interface
  if((debug != 20) && (debug != 30)){       //SNo: don't change debug-mode/menu when calcMinMax() or parameterMenu() are running
    double num;

    int state = userInput(num);
    #if ENABLE_PROGMODE > 0
    if(state == 10){executeProgCommand(par); state = 0;}
    #endif
    if(state == 1){
      debug = (int)num;
      Serial.println(debug);
      #ifdef HALLEFFECT
      // Debug is updated: check if the ADC referencevoltage has to be changed.
      setAnalogReferenceVoltage(debug);
      #endif
    }
    if(state == 2 || state == 3 || state == 4){debug = 99;}
    if((state != 0) && (debug == 0 || debug == 99)){showMenu = true;}

    if(showMenu){
      Serial.print(F("\r\n\r\nSpaceMouse FW"));Serial.print(F(FW_RELEASE));Serial.println(F(" - Debug Modes"));
      Serial.println(F("ESC stop running mode, leave menu (ESC, Q)"));
      Serial.println(F("  1 raw sensors ADC values full range, max. 0..1023"));
      #ifdef HALLEFFECT
      Serial.println(F(" 10 raw sensors ADC values used range, max. 0..1023"));
      #endif
      Serial.println(F("  2 centered values -500..+500"));
      Serial.println(F(" 11 auto calibrate centers, show deadzones"));
      Serial.println(F(" 20 find min/max-values over 20s (move stick)"));
      Serial.println(F("  3 centered values w.deadzones -350..+350"));
      Serial.println(F(" 31 drift compensation offsets"));
      Serial.println(F("  4 velocity- (trans-/rot-)values -350..+350"));
      Serial.println(F("  5 centered- & velocity-values, (3) and (4)"));
      Serial.println(F("  6 velocity after kill-keys and keys"));
      Serial.println(F(" 61 velocity after axis-switch, exclusive"));
      Serial.println(F("  7 loop-frequency-test"));
      Serial.println(F("  8 key-test, button-codes to send"));
      Serial.println(F("  9 encoder wheel-test"));
      #if PARAM_IN_EEPROM > 0
      Serial.println(F(" 30 parameters (load, save, edit, view)"));
      #endif
      Serial.print(F("mode::"));
      showMenu = false;
    }
  }

  //--- run parameter-menu
  if(debug == 30){
    #if PARAM_IN_EEPROM > 0
      if(parameterMenu(par) == 0){
        showMenu = true;
        debug = 0;
      }
    #else
      showMenu = true;
      debug = 0;
    #endif
  }

  //--- Read joystick values. 0-1023
  readAllFromJoystick(rawReads);

  //--- Reading of key presses
  #if NUMKEYS > 0
  readAllFromKeys(keyVals);
  #endif

  // Report back 0-1023 raw ADC 10-bit values if enabled
  #ifdef HALLEFFECT
  if ((debug == 1) || (debug == 10)) {
    debugOutput1(rawReads, keyVals);
  }
  #else
  if (debug == 1) {
    debugOutput1(rawReads, keyVals);
  }
  #endif

  //--- calibrate the joystick
  if (debug == 11) {
    // As this is called in the debug=11, we do more iterations.
    busyZeroing(centerPoints, 2000, true);
    debug = -1; // after function is done, leave this debug mode to "off" (-1)
  }

  //--- Calculate drift compensation offsets
  if((par.values->compEnabled == 1) && (debug != 20)){  // only when not in debug 20 = find min/max values
    compensateDrifts(rawReads, centerPoints, offsets, par);
  }else{
    for(int i = 0; i < 8; i++){offsets[i] = 0;}
  }

  // Report compensation-offset values
  if (debug == 31) {
    debugOutput2(offsets);
  }

  //--- Subtract centre position and drift-offsets from measured position to determine movement.
  for (int i = 0; i < 8; i++) {
    centered[i] = rawReads[i] - centerPoints[i] + offsets[i];
  }

  //--- calibrate MinMax values
  if (debug == 20) {
    // has to be (re-)called, as long as it doesn't signal "done"
    if(calcMinMax(centered) == 0){  // when calcMinMax() signals 0="done/idle":
      debug = -1;                   // leave this debug-mode 20 to "off" (-1)
    }
  }

  // Report centered joystick values if enabled. Values should be approx -350 to +350, jitter around 0 at idle
  if (debug == 2) {
    debugOutput2(centered);
  }

  //--- Set movement values to zero if movement is below deadzone threshold, scale to +/-350
  FilterAnalogReadOuts(centered, par);

  // Report centered joystick values. Filtered for deadzone. Approx -350 to +350, locked to zero at idle
  if (debug == 3) {
    debugOutput2(centered);
  }

  //--- Calculate the kinematic (centered->velocity)
  calculateKinematic(centered, velocity, par);

  //--- if an encoder wheel is used, calculate the velocity of the wheel
  //    and replace one of the former calculated velocities
  #if (ROTARY_AXIS > 0) && (ROTARY_AXIS < 7)
  calcEncoderWheel(velocity, (debug == 9), par);
  #endif

  //--- if defined, evaluate keys
  #if NUMKEYS > 0
  evalKeys(keyVals, keyOut, keyState);
  #endif








// === Build HID keys with FN1+FN2 zero hotkey ===
uint8_t hidKeys[NUMKEYS];
memcpy(hidKeys, keyState, NUMKEYS);

// Требуются индексы Fn из config.h:
const bool hasFn1 = (KEY_FN1_IDX < NUMKEYS) ? (hidKeys[KEY_FN1_IDX] != 0) : false;
const bool hasFn2 = (KEY_FN2_IDX < NUMKEYS) ? (hidKeys[KEY_FN2_IDX] != 0) : false;

// Никаких других базовых кнопок в момент удержания:
bool anyOther = false;
for (int i = 0; i < NUMHIDKEYS; ++i) {
  if (i == KEY_FN1_IDX || i == KEY_FN2_IDX) continue;
  if (hidKeys[i]) { anyOther = true; break; }
}

// Армирование и срабатывание
if (hasFn1 && hasFn2 && !anyOther && millis() >= g_fnZeroCooldownUntil) {
  if (!g_fnZeroPending) {
    g_fnZeroPending = true;
    g_fnZeroStart = millis();
  }
  // Пока ждём вторую секунду — подавляем любые HID-кнопки полностью:
  for (int i = 0; i < NUMKEYS; ++i) hidKeys[i] = 0;

  if (millis() - g_fnZeroStart >= FN_ZERO_HOLD_MS) {
    // Тихое зануление центров (НЕ трогаем min/max, сенсы и т.д.)
    busyZeroing(centerPoints, FN_ZERO_SAMPLES, /*debugPrint=*/false);
    g_fnZeroPending = false;
    g_fnZeroCooldownUntil = millis() + FN_ZERO_COOLDOWN_MS;
  }
} else {
  g_fnZeroPending = false;
}











  // The encoder wheel shall be treated as a key
  #if ROTARY_KEYS > 0 
  // The encoder wheel shall be treated as a key
  calcEncoderAsKey(keyState, (debug == 9));
  #endif

  // report translation and rotation values if enabled
  if (debug == 4) {
    debugOutput4(velocity, keyOut);
  }

  if (debug == 5) {
    debugOutput5(centered, velocity);
  }

  // if the kill-key feature is enabled, rotations or translations are killed=set to zero
  #if (NUMKILLKEYS == 2)
  if (keyVals[KILLROT] == LOW) {  
    // check for the raw keyVal and not keyOut, because keyOut is only 1 for a single iteration. keyVals has inverse Logic due to pull-ups
    // kill rotation
    velocity[ROTX] = 0;
    velocity[ROTY] = 0;
    velocity[ROTZ] = 0;
  }
  if (keyVals[KILLTRANS] == LOW) {
    // kill translation
    velocity[TRANSX] = 0;
    velocity[TRANSY] = 0;
    velocity[TRANSZ] = 0;
  }
  #endif

  // report velocity and keys after possible kill-key feature
  if (debug == 6) {
    debugOutput4(velocity, keyOut);
  }

  //--- exchange axis if desired
  if(par.values->switchYZ == 1) {switchYZ(velocity);}
  if(par.values->switchXY == 1) {switchXY(velocity);}

  // exclusive mode: rotation OR translation, but never both at the same time to avoid issues with classics joysticks
  if(par.values->exclusiveMode == 1){
    exclusiveMode(velocity, par.values->exclusiveHysteresis);
  }

  // report velocity and keys after Switch or ExclusiveMode
  if(debug == 61){
    debugOutput4(velocity, keyOut);
  }

  // SpaceMouseHID.send_command(velocity[ROTX], velocity[ROTY], velocity[ROTZ], velocity[TRANSX], velocity[TRANSY], velocity[TRANSZ], keyState, debug);
  SpaceMouseHID.send_command(velocity[ROTX], velocity[ROTY], velocity[ROTZ], velocity[TRANSX], velocity[TRANSY], velocity[TRANSZ], hidKeys, debug);

  // update and report at what frequency the loop is running
  if(debug == 7){
    updateFrequencyReport();
  }

  // Check for the LED state by calling updateLEDState.
  // This empties the USB input buffer and checks for the corresponding report.
  SpaceMouseHID.updateLEDState();

  #ifdef LEDpin
  #ifdef LEDRING
  processLED(velocity, SpaceMouseHID.getLEDState());
  #else
  lightSimpleLED(SpaceMouseHID.getLEDState());
  #endif
  #endif

} //end loop()


#ifdef LEDpin
/// @brief Turn on or off a simple led. The pin is defined by LEDpin in config.h. If the LED needs to be inverted, define LEDinvert in config.h
/// @param light turn on or off
void lightSimpleLED(boolean light){
  // Check for the LED state by calling updateLEDState.
  // This empties the USB input buffer and checks for the corresponding report.
  #ifdef LEDinvert
  // Swap the LED logic, if necessary
  if (light){
  #else
  if (!light){
  #endif
    digitalWrite(LEDpin, LOW);  // LED on -> pull kathode down
  }else{
    digitalWrite(LEDpin, HIGH); // LED off -> pull kathode up
  }
}
#endif


#ifdef HALLEFFECT
/**
 * @brief Set the analog reference to 5V for debug 1 and to 2.56V otherwise
 */
void setAnalogReferenceVoltage(int dbg){
  if (dbg == 1){  // Set the reference voltage for the AD Convertor to 5V only for the first calibration step (pinout/inversion calibration).
    analogReference(DEFAULT);
    #ifdef DEBUG_ADC
      Serial.println(F("Setting analog reference to 5V."));
    #endif
  }else{          // Set the reference voltage for the AD Convertor to 2.56V in order to get larger sensitivity.
    analogReference(INTERNAL);
    #ifdef DEBUG_ADC
      Serial.println(F("Setting analog reference to 2.56V."));
    #endif
  }

  // The first measurements after changing the reference voltage can be wrong. So take 100ms to let the voltage stabilize and
  // take some measurements afterwards just to be sure. Performancewise this isn't a problem due to the debug/setup
  // nature of this function.
  delay(100);
  int tempReads[8];
  for (int i = 0; i <= 8; i++){
    readAllFromJoystick(tempReads);
  }
}
#endif

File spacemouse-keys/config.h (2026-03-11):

#ifndef CONFIG_h
#define CONFIG_h

#include "release.h"

#define PARAM_IN_EEPROM 1
#define ENABLE_PROGMODE 1

#undef  DEBUG_KEYS
#undef  DEBUG_ADC

/* The user specific settings, like pin mappings or special configuration variables and sensitivities are stored in config.h.
   This file is meant for the << HALL-EFFECT SPACEMOUSE >>
   Please adjust your settings and save it as --> config.h <-- !
*/


/* Calibration Instructions
============================
Follow this file from top to bottom to calibrate your space mouse.
You can find some pictures for the calibration process here:
https://github.com/AndunHH/spacemouse/wiki/Ergonomouse-Build#calibration

Debugging Instructions
=========================
To activate one of the following debugging modes, you can either:
- Change STARTDEBUG here in the code and compile/download again
  OR
- Compile and upload the program. Go to the serial monitor and type the number and hit enter to select the debug mode.

Debug Modes:
------------
-1: Debugging off. Set to this once everything is working.
0:  Nothing...

1:  Report raw joystick values on 5V ref.    0-1023 raw ADC 10-bit values
10: Report raw joystick values on 2.56V ref. 0-1023 raw ADC 10-bit values
11: Calibrate / Zero the SpaceMouse and get a dead-zone suggestion (This is also done on every startup in the setup())

2:  Report centered joystick values. Values should be approximately -500 to +500, jitter around 0 at idle.
20: semi-automatic min-max calibration.

3:  Report centered joystick values. Filtered for deadzone. Approximately -350 to +350, locked to zero at idle, modified with a function.

4:  Report translation and rotation values. Approximately -350 to +350 depending on the parameter.
5:  Report debug 3 and 4 side by side for direct cause and effect reference.
6:  Report velocity and keys after possible kill-key feature
61: Report velocity and keys after kill-switch or ExclusiveMode
7:  Report the frequency of the loop() -> how often is the loop() called in one second?
8:  Report the bits and bytes send as button codes
9:  Report details about the encoder wheel, if ROTARY_AXIS > 0 or ROTARY_KEYS>0
*/

#define STARTDEBUG 0  // Can also be set over the serial interface, while the programm is running!

// Hardware uses HallEffect sensors instead of joystick sensors
#define HALLEFFECT

/* First Calibration: Hall effect sensors pin assignment, electrical check
=========================================================================== */
#define PINLIST \
  { A0,   A1,   A2,   A3,   A6,   A7,   A8,   A9 }
// HES0, HES1, HES2, HES3, HES6, HES7, HES8, HES9

#define INVERTLIST \
  {  0,    0,    0,    0,    0,    0,    0,    0 }
// HES0, HES1, HES2, HES3, HES6, HES7, HES8, HES9

/* Second calibration: Tune Deadzone
===================================== */
#define DEADZONE 5 // Recommended to have this as small as possible to allow full range of motion. // <<

/* Third calibration: Getting MIN and MAX values
================================================= */
//              {HES0, HES1, HES2, HES3, HES6, HES7, HES8, HES9}
// #define MINVALS {-335, -323, -379, -305, -388, -305, -381, -422}
// #define MAXVALS {118, 123, 144, 143, 113, 161, 103, 135}
#define MINVALS {-335, -323, -379, -305, -388, -305, -381, -422}
#define MAXVALS {118, 123, 144, 143, 113, 161, 103, 135}


/* Fourth calibration: Sensitivity
=================================== */
#define SENS_TX     0.55   // << консоль param::2
#define SENS_TY     0.62   // << param::3
#define SENS_PTZ    1.92   // sensitivity for positive translation z // <<
#define SENS_NTZ    1.30   // sensitivity for negative translation z // <<

#define GATE_NTZ    0     // gate for negative z (0 = off) // <<
#define GATE_RX     0     // Value under which rotX forced to zero // <<
#define GATE_RY     0     // Value under which rotY forced to zero // <<
#define GATE_RZ     0     // Value under which rotZ forced to zero // <<

#define SENS_RX     1.40  // << param::10
#define SENS_RY     1.36  // << param::11
#define SENS_RZ     0.81  // << param::12

/* Fifth calibration: Modifier Function
======================================== */
#define MODFUNC       1     // was 0 -> now “squared” curve // <<
#define MOD_A         1.15  // exponent "a"
#define MOD_B         1.25  // factor "b" // <<

/* Sixth Calibration: Direction
================================ */
// Switch between 0 or 1 as desired
#define INVX  0 // pan left/right                          // 3Dc: 0
#define INVY  1 // pan up/down                             // 3Dc: 1
#define INVZ  1 // zoom in/out                             // 3Dc: 1
#define INVRX 1 // Rotate around X axis (tilt front/back)  // 3Dc: 0 // <<
#define INVRY 0 // Rotate around Y axis (tilt left/right)  // 3Dc: 1 // <<
#define INVRZ 0 // Rotate around Z axis (twist left/right) // 3Dc: 1 // <<

#define SWITCHYZ 0
#define SWITCHXY 0
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

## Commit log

2025-11-03 Add some shit
    [modifierFunctions.ods, spacemouse.fzz]
2026-03-11 First version of 3d-case
    [Base.stp, Handle.stp, HandleCap.stp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]
2026-03-15 Some new DIY solutions
    [obj_10_top support.stl, obj_11_standard base.stl, obj_12_base 2.5 più.stl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]
